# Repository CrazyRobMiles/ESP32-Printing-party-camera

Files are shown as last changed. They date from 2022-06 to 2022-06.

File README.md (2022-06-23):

# Printing Party Camera
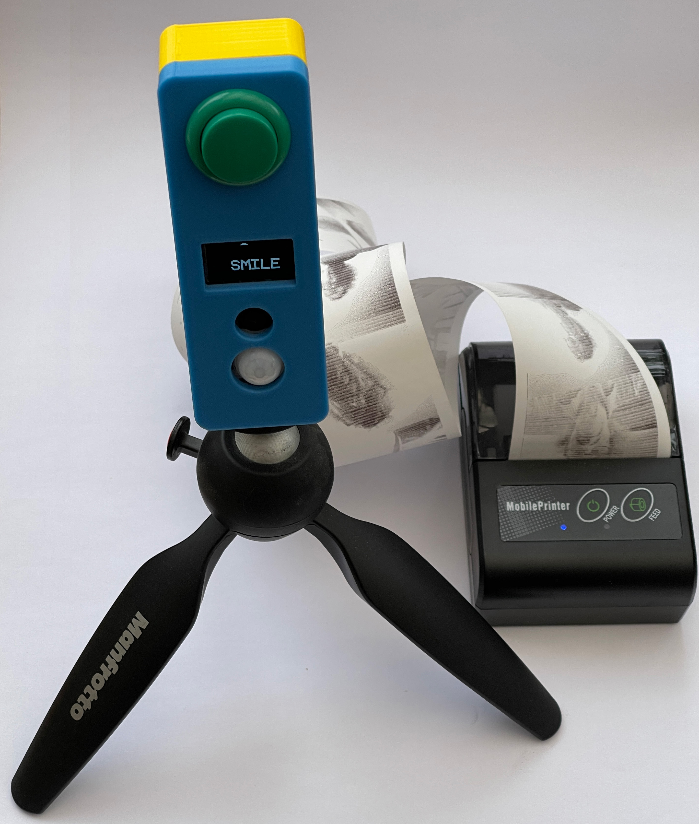
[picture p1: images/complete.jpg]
Camera and printer

Designs and software for an ESP32 powered device that will take pictures and print them on a Bluetooth printer.
## Instuctions
The camera wakes up when the PIR sensor is triggered. It initialises the on board camera and searches for a compatible Bluetooth printer. If it finds one it displays a message and waits for the button to be pressed. When the button is pressed the camera shows a five second countdown and then takes and prints a picture. 

If the camera PIR sensor is not triggered for 30 seconds the camera will shut down until the PIR sensor is triggered again. 

If the camera can't start running (perhaps the printer is not switched on) it will retry five times and then shut down if the PIR sensor is not triggered. 
## Parts list
* Bluetooth thermal printer. Search for “Mini Portable Bluetooth Thermal Printer”. They are usually supplied with a small roll of 57mm wide thermal paper. You can get more from any office supply shop.
* ESP-32 camera board. The “TTGO esp32 camera” unit is perfect for this project. It contains a display and a PIR sensor to wake up the camera. Search for it by name. 
Battery. The TTGO device can connect to a rechargeable battery. Search for “1000mAh 802540 3.7 volt” if you want one that works with the case design.
* A button to activate the camera. Search for “24mm arcade button”.  The author used wire wrap wire to connect the button to the TTGO. You can also get a connector that you can use rather than wire wrap. Search for “TTGO camera cable”.
* A box. There is a 3D printable design available. If you want to put the camera on a tripod you will need a 3/8" to 1/4" camera adapter which you can search for by name. 
* Screws. You'll need some screws side M2 4mm in length to fix the TTGO device to the case (search for "laptop screws").
* Micro USB cable. You program and power the camera via the micro-usb cable on the TTGO cable. 
## Hardware
The button is connected between the GND and IO22 connections on the TTGO board expansion connector. You can do this by connecting to the pins inside the connector, by soldering onto the connector at the back or by using the TTGO expansion cable which is also available.
# Party Camera Software
To use the software just open this folder into PlatformIO and build it. All the required versions of the drivers are part of the project. 
# Case
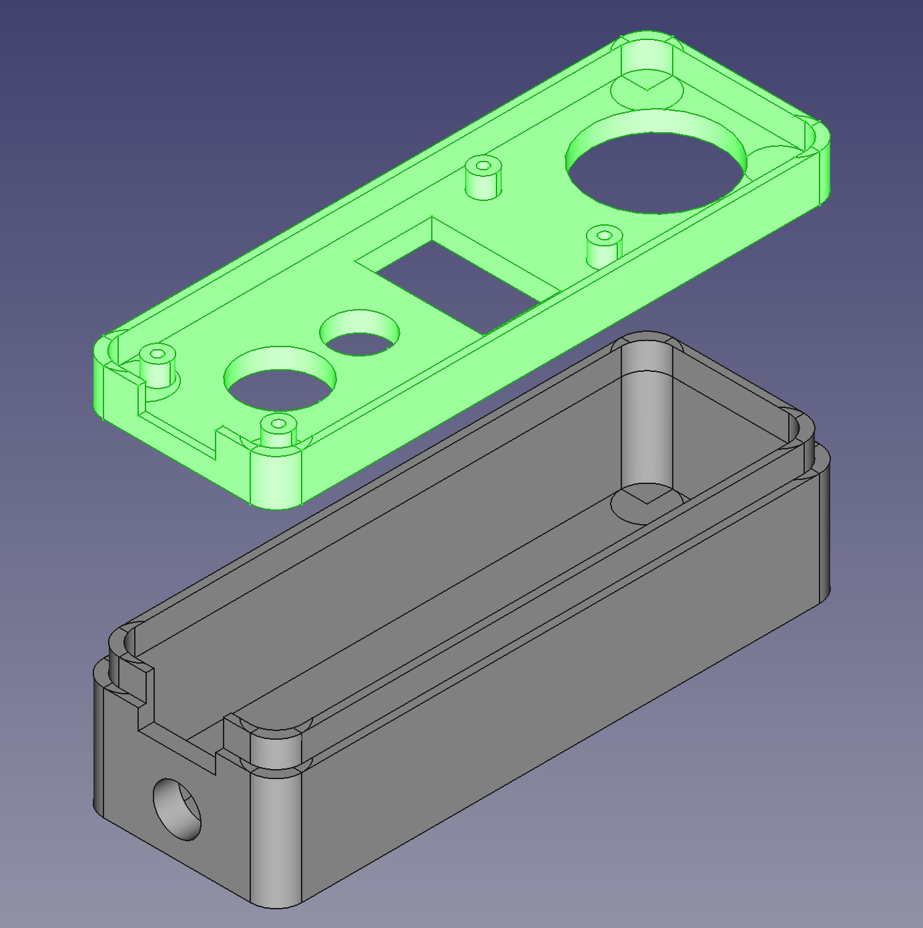
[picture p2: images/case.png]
case design in FreeCAD

The [case](/case) folder holds printable designs for the top and bottom of a case along with the Python macro that runs inside [FreeCAD](https://www.freecadweb.org/).

# Troubleshooting
## PlatformIO not running
If PlatformIO fails to show you any build or run options for the project, make sure that you have installed the extension and that it is enabled for your workspace. Open the file main.cpp in the src folder to trigger the PlatformIO toolbar.

If the camera device is not detected when you plug it into usb you might need to disable other extensions that use the serial port. 
## Printer not recognised
If the camera gets stuck on the 'CAMERA OK' screen during startup it might be that your Bluetooth printer hasn't been recognised. The [GitHub site ](https://github.com/bitbank2/Thermal_Printer) for the printer library has a list of printers that are supported. If your printer is in the list you can try adding its name to the printer library.  The file to modify is Thermal_Printer.cpp in the folder *\software\.pio\libdeps\esp-wrover-kit\Thermal Printer Library* 

The printer names are defined on line 59 of the file. To make the printer code work with my printer I had to change the name of the first printer to the  Bluetooth name of my printer, which was MPT-II. 

```
const char *szBLENames[] = {(char *)"MPT-II",
```

I used the program BLE Scanner from [Blue Pixel Tech](https://www.bluepixeltech.com) on my mobile phone to find the Bluetooth name of the printer and then changed the  string in the file match this. 
## Program Speed
The PlatformIO ini file for this project contains a setting that reduces the clock speed of the ESP32 to 16 MHz. This has been found to make the camera setup more reliable. If you reuse this code in another project you must make sure that you add this setting.
## Program Size
The ESP32 code uses the Bluetooth libraries which are rather large. This project configures the build to produce the "Huge App" version of the code. This is selected in the PlatformIO.ini file. If you reuse this code in another project you must make sure you add this setting. 
## Acknowledgements
The code for the camera uses the [Thermal Printer](https://github.com/bitbank2/Thermal_Printer) and [JPEGDEC](https://github.com/bitbank2/JPEGDEC) libraries from Larry Bank which is are excellent free resources. Thanks very much. 

Thanks also go to Robot Zero One for their [fridge guard](https://robotzero.one/ttgo-security-camera-pir/) project which provided very useful tips for starting the camera using the PIR sensor. 

Have fun

Rob Miles

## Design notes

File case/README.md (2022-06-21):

The case has no overhangs, although it is sensible to turn on internal support for the tripod hole. The tripod adapter should be fitted from the inside of the case. If it seems a little loose after you have screwed it into place you can add a spot of hot glue.

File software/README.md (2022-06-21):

# Party Camera Software

To use the software just load the folder into PlatformIO and build it. All the required versions of the drivers are part of the project. 
## Adding a different printer
You only need to do this if your printer is not recognised by the thermal printer libaray. The [GitHub site ](https://github.com/bitbank2/Thermal_Printer) for the printer code has a list of printers that are already supported. 

To make the printer code work with my printer I had to modify a file in the library code and add the Bluetooth name of my printer. 

 The file to modify is Thermal_Printer.cpp in the folder *\software\.pio\libdeps\esp-wrover-kit\Thermal Printer Library* 

The printer names are defined on line 59 of the file:

```
const char *szBLENames[] = {(char *)"MPT-II",
```

I used the program BLE Scanner from [Blue Pixel Tech](https://www.bluepixeltech.com) on my mobile phone to find the Bluetooth name of the printer and then changed the first string in the file match this. 
## The camera and CPU Speed
The PlatformIO ini file for this project contains a setting that reduces the clock speed of the ESP32 to 16 MHz. This has been found to make the camera setup more reliable. If you reuse this code in another project you must make sure that you add this setting.
## The camera and the Bluetooth stack
The ESP32 code uses the Bluetooth libraries which are rather large. This project configures the build to produce the "Huge App" version of the code. This is selected in the PlatformIO.ini file If you reuse this code in another project you must make sure you add this setting.

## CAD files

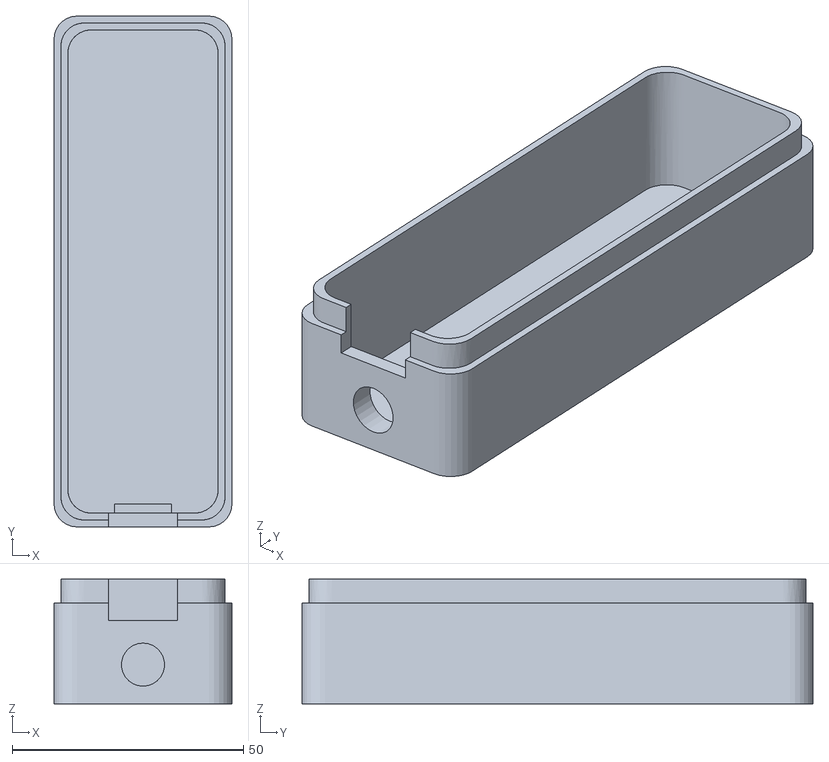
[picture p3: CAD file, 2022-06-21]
case/bottom.stl
38.5 x 110.5 x 27.0

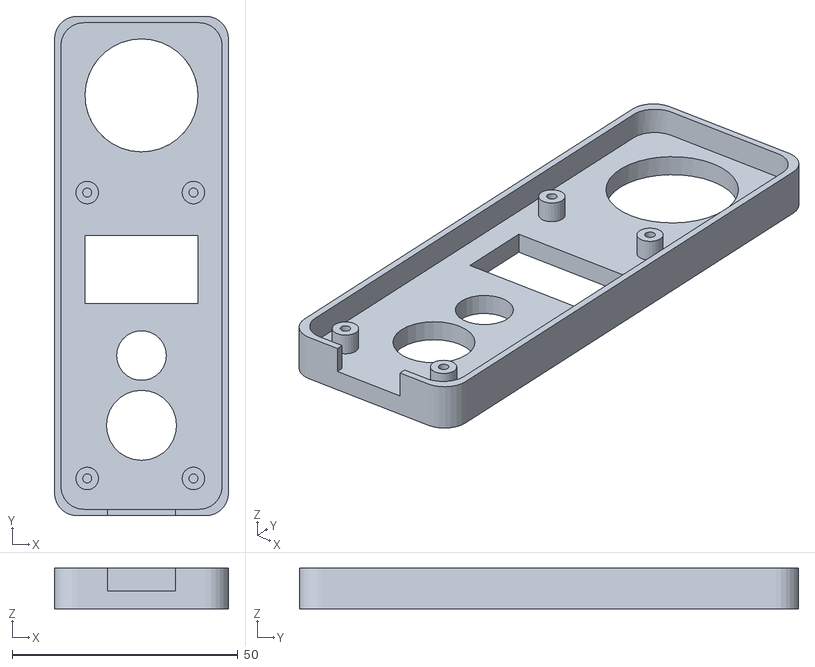
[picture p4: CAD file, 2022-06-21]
case/top.stl
38.5 x 110.5 x 9.00

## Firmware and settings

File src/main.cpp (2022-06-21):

#include <Arduino.h>
#include <Thermal_Printer.h>
#include <JPEGDEC.h>
#include <U8g2lib.h>
#include "OV2640.h"
#include "U8x8lib.h"
#include <esp_camera.h>

U8X8_SSD1306_128X64_NONAME_SW_I2C u8x8(/* clock=*/22, /* data=*/21);

#define PIR_PIN 33
#define SHUTTER_PIN 22

OV2640 cam;
JPEGDEC jpg;

uint8_t ucDither[576 * 16]; // buffer for the dithered pixel output

// Called when the decoder has a batch of pixels to print
int printRows(JPEGDRAW *pDraw)
{
  int i, iCount;
  uint8_t *s = (uint8_t *)pDraw->pPixels;

  tpSetBackBuffer((uint8_t *)pDraw->pPixels, pDraw->iWidth, pDraw->iHeight);
  // The output is inverted, so flip the bits
  iCount = (pDraw->iWidth * pDraw->iHeight) / 8;
  for (i = 0; i < iCount; i++){
    s[i] = ~s[i];
  }

  tpPrintBuffer(); // Print this block of pixels
  return 1;        // Continue decode
}

bool last_shutter_input;

void setup_shutter()
{
  Serial.println("Setting up shutter");
  pinMode(SHUTTER_PIN, INPUT_PULLUP);
  last_shutter_input = digitalRead(SHUTTER_PIN);
}

#define PIR_PIN 33

void setup_pir()
{
  Serial.println("Setting up PIR");
  pinMode(PIR_PIN, INPUT);
  esp_sleep_enable_ext0_wakeup((gpio_num_t)PIR_PIN, HIGH);
}

void setup_display()
{
  Serial.println("Setting up display");
  u8x8.setPowerSave(false);
  u8x8.begin();
  u8x8.setFont(u8x8_font_profont29_2x3_r);
  u8x8.setFlipMode(1);
}

bool try_setup_camera()
{
  Serial.println("Setting up camera:");

  esp_err_t res = cam.init(esp32cam_ttgo_t_config);

  if (res == ESP_OK)
  {
    Serial.println("   camera OK");
    return true;
  }
  else
  {
    Serial.println("   camera setup failed");
    return false;
  }
}

bool try_setup_bluetooth_printer()
{
  Serial.println("Setting up printer:");
  if (tpScan())
  {
    if (tpConnect())
    {
      Serial.println("   printer found");
      tpSetWriteMode(MODE_WITHOUT_RESPONSE);
      Serial.println("   printer connected");
      return true;
    }
    else
    {
      Serial.println("   no printer");
      return false;
    }
  }
  else
  {
    Serial.println("   failed");
    return false;
  }
}

bool try_setup(bool (*try_setup_function)(),
               int retry_gap_millis,
               int no_of_retries)
{
  while ((no_of_retries--) > 0)
  {
    if (try_setup_function())
      return true;
    delay(retry_gap_millis);
    Serial.print("    retry");
  }
  Serial.print("    failed");
  return false;
}

uint8_t *frame_buffer = NULL;
int frame_buffer_size;

void take_picture()
{
  Serial.println("   taking a picture");
  frame_buffer = (uint8_t *)cam.getfb();
  frame_buffer_size = cam.getSize();
}

void print_picture()
{
  Serial.println("   printing the picture");
  
  if (jpg.openRAM(frame_buffer, frame_buffer_size, printRows))
  {
    Serial.println("   picture decoded");
    jpg.setPixelType(ONE_BIT_DITHERED);
    jpg.decodeDither(ucDither, JPEG_SCALE_HALF);
  }
}

unsigned long start_time;
#define TIMEOUT_MILLISECS 30000

void show_hello()
{
  u8x8.setCursor(3, 2);
  u8x8.print("HELLO");
}

void show_camera_ok()
{
  u8x8.clear();
  u8x8.setCursor(3, 0);
  u8x8.print("CAMERA");
  u8x8.setCursor(6, 4);
  u8x8.print("OK");
}

void show_printer_ok()
{
  u8x8.clear();
  u8x8.setCursor(1, 0);
  u8x8.print("PRINTER");
  u8x8.setCursor(6, 4);
  u8x8.print("OK");
}

void show_smile(int count)
{
  char buffer[20];
  snprintf(buffer, 20, "%d", count);
  u8x8.clear();
  u8x8.setCursor(6, 0);
  u8x8.print(buffer);
  u8x8.setCursor(4, 4);
  u8x8.print("SMILE");
}

void show_click()
{
  u8x8.clear();
  u8x8.setCursor(0, 2);
  u8x8.print("*CLICK*");
}

void show_goodbye()
{
  u8x8.clear();
  u8x8.setCursor(0, 2);
  u8x8.print("GOODBYE");
}

void show_print()
{
  u8x8.clear();
  u8x8.setCursor(3, 2);
  u8x8.print("PRINT");
}

void show_press_button()
{
  u8x8.clear();
  u8x8.setCursor(3, 0);
  u8x8.print("PRESS");
  u8x8.setCursor(2, 4);
  u8x8.print("BUTTON");
}

void take_picture_and_print()
{
  Serial.println("Taking a picture and printing:");
  Serial.println("   countdown");

  delay(200);

  for (int i = 5; i > 0; i--)
  {
    show_smile(i);
    delay(1000);
    cam.run();
    frame_buffer = (uint8_t *)cam.getfb();
  }

  show_click();
  take_picture();
  show_print();
  print_picture();
  show_press_button();
}

void go_to_sleep()
{
  Serial.println("Device Sleeping...");
  show_goodbye();
  delay(1000);
  // turn off the screen
  u8x8.setPowerSave(true);
  // disconnect the printer
  tpDisconnect();
  // turn off bluetooth
  btStop();
  // enter deep sleep
  esp_deep_sleep_start();
}

void update_shutter_button()
{
  bool new_shutter = digitalRead(SHUTTER_PIN);
  if (last_shutter_input != new_shutter) {
    if (new_shutter == 0) {
      take_picture_and_print();
    }
    last_shutter_input = new_shutter;
  }
}

void update_timeout()
{
  unsigned long timer_millis = millis();
  if (digitalRead(PIR_PIN)) {
    // reset the timer if people are still in front of
    // the camera
    start_time = timer_millis;
  }

  if ((timer_millis - start_time) > TIMEOUT_MILLISECS) {
    // turn off the camera
    go_to_sleep();
  }
}

void setup()
{
  Serial.begin(115200);
  setup_shutter();
  setup_display();
  setup_pir();

  if (!digitalRead(PIR_PIN)) {
    // shut down if nobody is in front of the camera
    go_to_sleep();
  }

  show_hello();

  if (!try_setup(try_setup_camera, 200, 5))
  {
    Serial.println("*** CAMERA START FAILED");
    esp_restart();
  }

  show_camera_ok();

  if (!try_setup(try_setup_bluetooth_printer, 200, 5))
  {
    Serial.println("*** PRINTER START FAILED");
    esp_restart();
  };

  show_printer_ok();

  delay(200);

  show_press_button();
}

void loop()
{
  update_shutter_button();
  update_timeout();
  delay(10);
}

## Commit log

2022-06-21 Initial release
    [bottom.stl, top.stl]
2022-06-21 Added hardware description for the button.
